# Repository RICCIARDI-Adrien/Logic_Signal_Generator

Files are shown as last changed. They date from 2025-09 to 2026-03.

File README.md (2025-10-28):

# Logic Signal Generator

A versatile multi-protocol 1.8V/3.3V/5V logic signal generator powered by a PIC18F25K50.

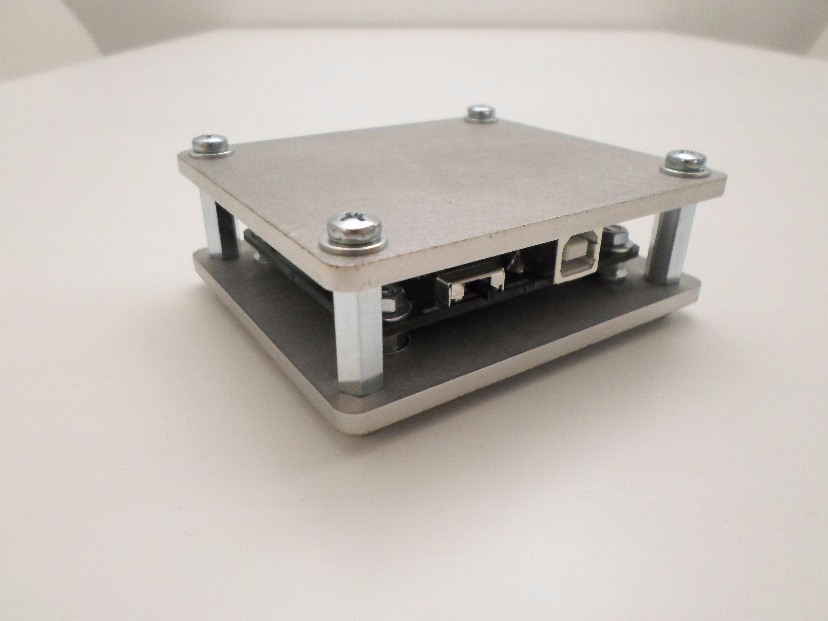
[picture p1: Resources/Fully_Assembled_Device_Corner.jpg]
Fully assembled device corner


## Features

* 8 independant channels featuring several standard protocols.
* The microcontroller hardware I2C, UART, SPI and PWM modules are used to provide the signal timings.
* Entirely USB-powered, no need for an external power supply.
* Dedicated power supplies and ground connector to easily power the device under test. The embedded 1.8V and 3.3V power supplies are each able to provide 500mA (these power supplies are derived from the USB power, so the available power could be limited by the USB port).
* On-board switch to quickly select the logic signals output voltage (1.8V, 3.3V or 5V).
* The USB interface is managed by the microcontroller itself and provides a standard USB serial port to the host.
* Simple shell-based text interface through the serial port to interactively configure and define the logic signals to generate.
* The signals are doubled on the output connector to easily connect a logic analyzer.
* PICkit-compatible standard connector to easily program the on-board microcontroller firmware.
* Compact and robust casing designed to bring the signal generator on field.

## Hardware

Bare PCB :
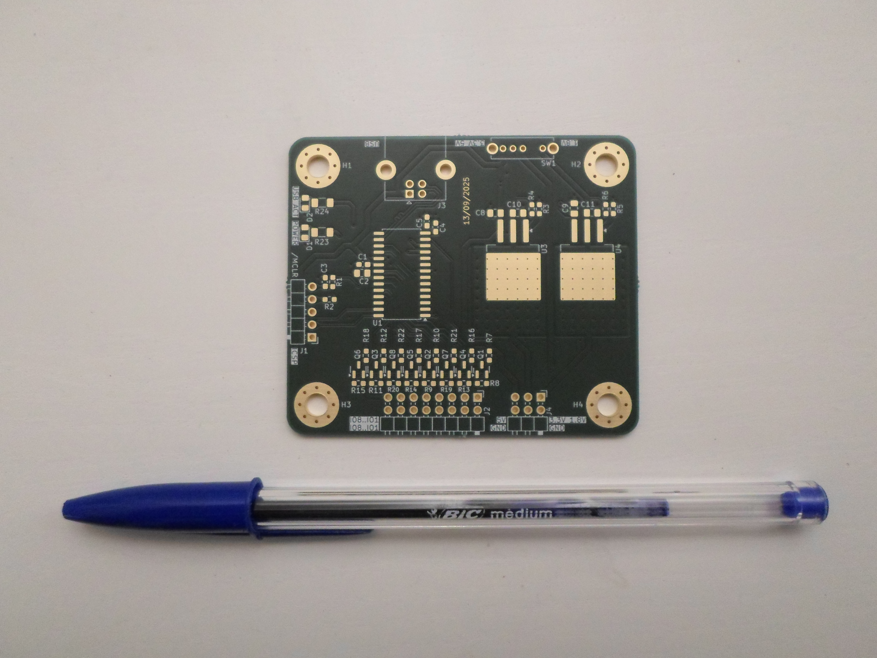
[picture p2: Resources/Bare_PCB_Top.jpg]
Bare PCB front view

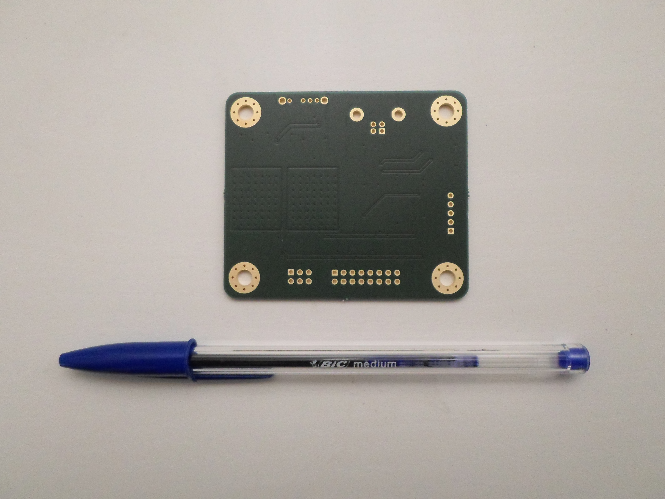
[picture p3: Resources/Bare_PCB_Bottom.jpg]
Bare PCB bottom view


Assembled PCB :
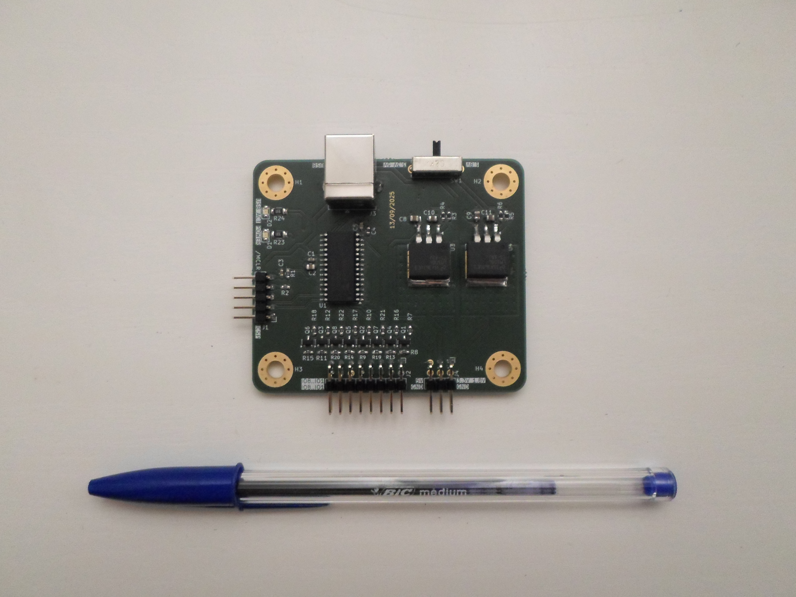
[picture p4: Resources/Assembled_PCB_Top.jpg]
Assembled PCB front view

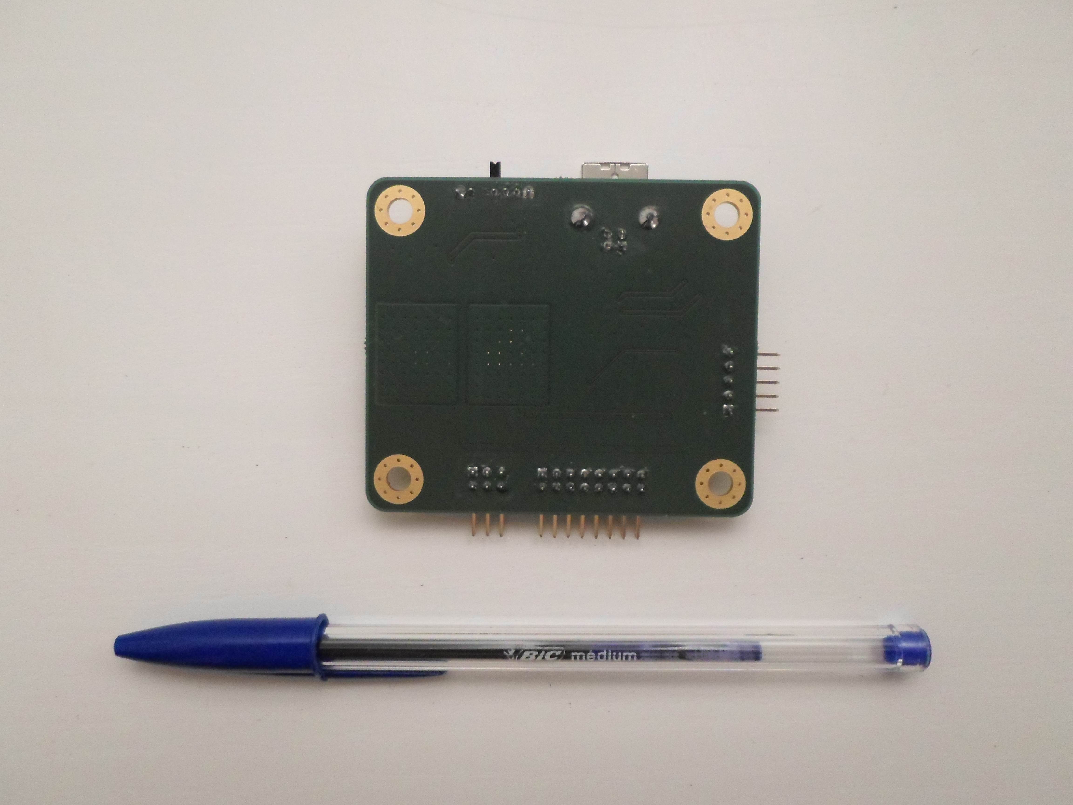
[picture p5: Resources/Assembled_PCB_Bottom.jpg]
Assembled PCB bottom view


## Casing

The casing is made of 4mm-thick 304 stainless steel.

Bare plates :
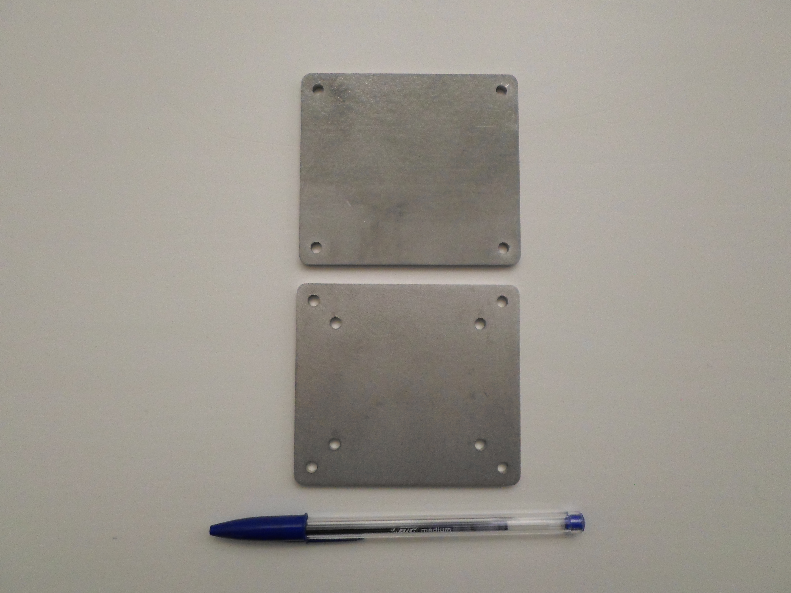
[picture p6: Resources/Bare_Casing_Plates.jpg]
Bare plates


Assembled bottom plate, with PCB and hex spacers :
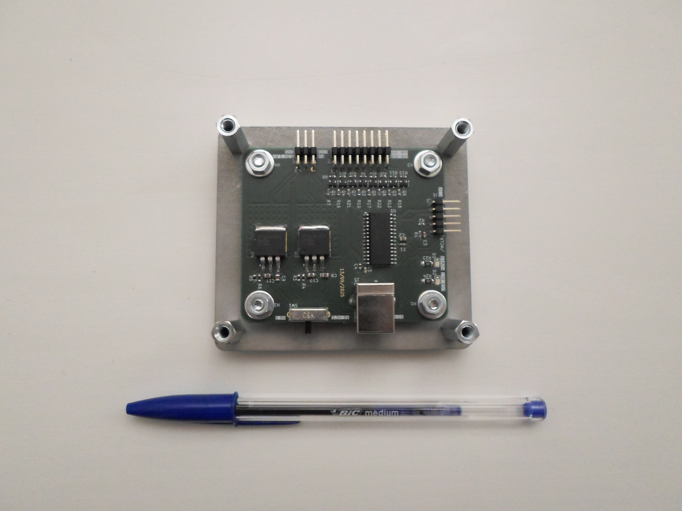
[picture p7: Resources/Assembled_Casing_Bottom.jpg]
Assembled bottom plate


Fully assembled device :  
Top view :
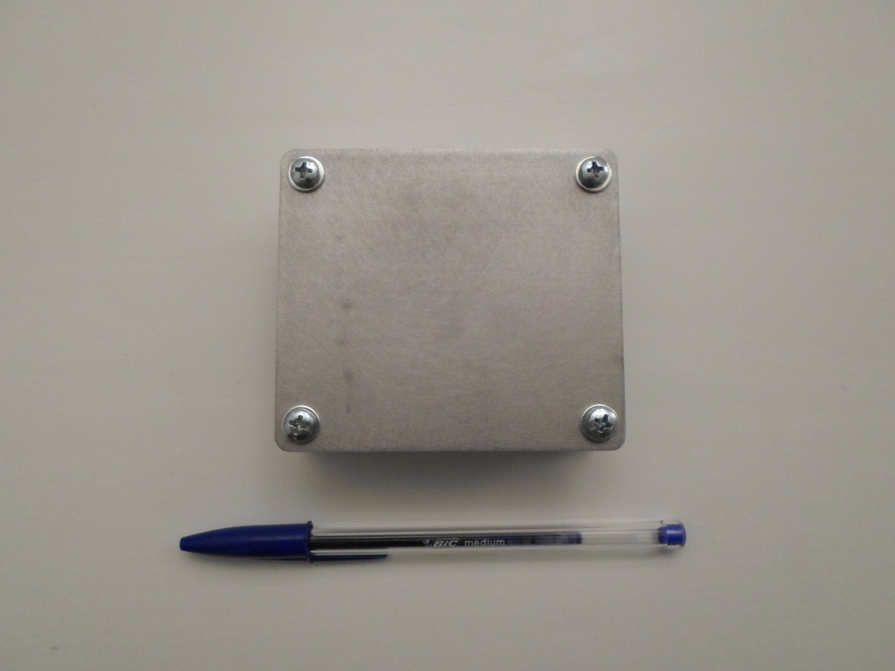
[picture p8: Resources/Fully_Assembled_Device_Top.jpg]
Fully assembled device

IO and power connectors :
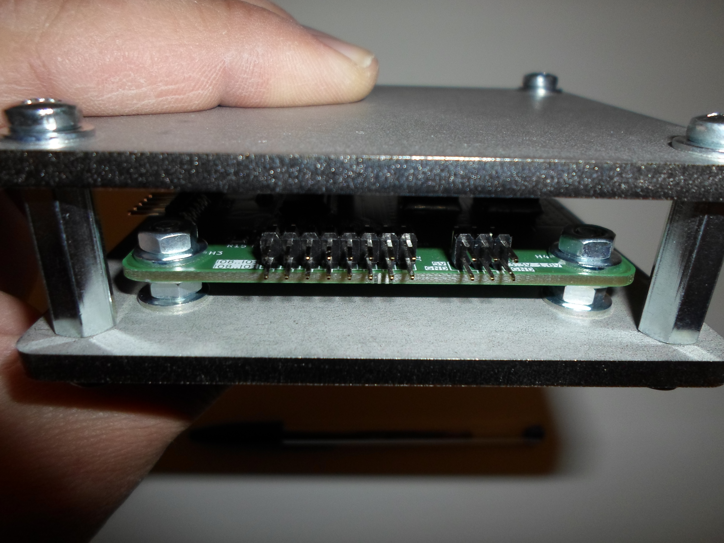
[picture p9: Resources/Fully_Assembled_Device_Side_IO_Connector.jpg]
Fully assembled device side IO connector

USB connector and IO voltage selection switch :
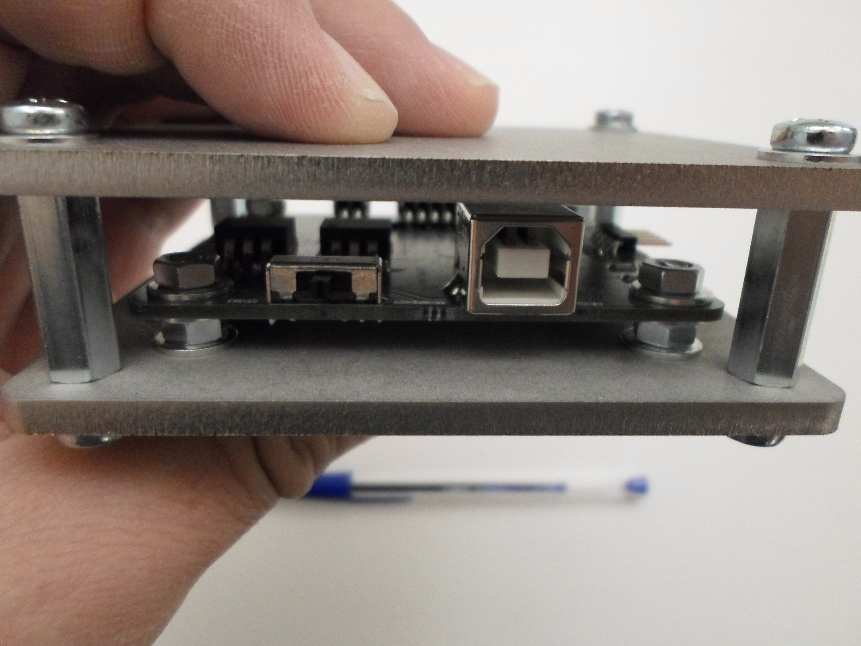
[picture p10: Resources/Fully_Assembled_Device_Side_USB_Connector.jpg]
Fully assembled device side USB connector

Power and activity LEDs along with microcontroller programming connector :
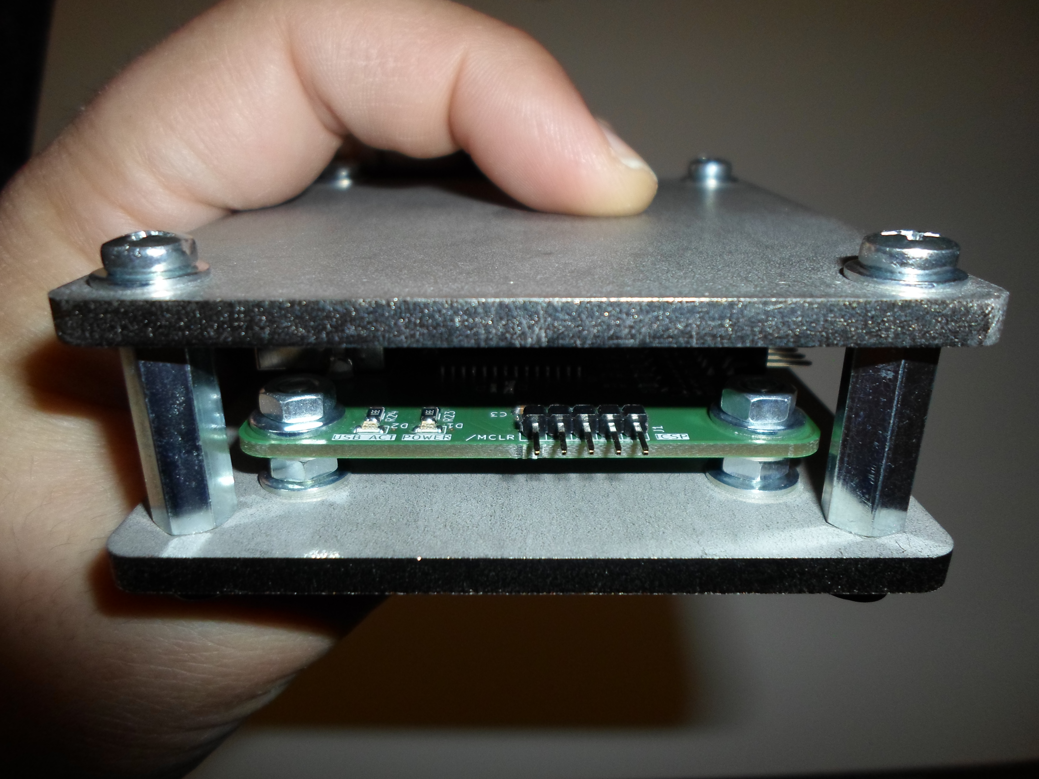
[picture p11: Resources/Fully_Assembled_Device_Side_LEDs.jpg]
Fully assembled device side LEDs


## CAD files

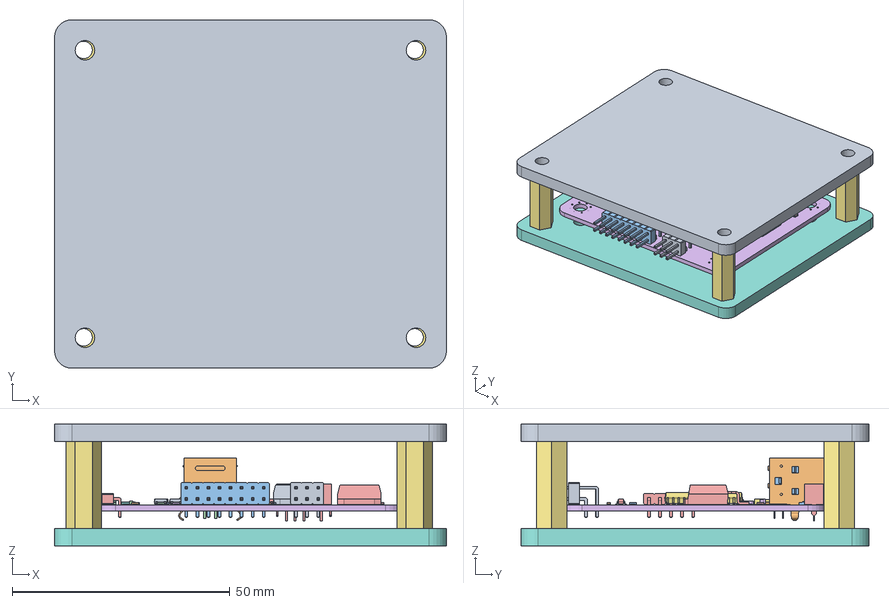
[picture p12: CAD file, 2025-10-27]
Casing/Casing.FCStd
90.0 x 80.0 x 28.0 mm
SOT-23
R_0603_1608Metric
R_0603_1608Metric001
C_0603_1608Metric
OS103011MA7QP1
SOT-024
R_0603_1608Metric002
C_0603_1608Metric001
R_0603_1608Metric003
_USB-B-S-TH_S
_USB-B-S-B-TH_B
_USB-B-S-TH_P
R_0603_1608Metric004
R_0603_1608Metric005
C_0805_2012Metric
SOT-025
PinHeader_2x03_P2.54mm_Horizontal
R_0603_1608Metric006
R_0603_1608Metric007
R_0603_1608Metric008
C_0805_2012Metric001
C_0805_2012Metric002
LED_0805_2012Metric
R_1206_3216Metric
SOT-026
R_1206_3216Metric001
R_0603_1608Metric009
LED_0805_2012Metric001
Logic_Signal_Generator_PCB 1.27.1
R_0603_1608Metric010
SOIC-28W_7.5x17.9mm_P1.27mm
R_0603_1608Metric011
R_0603_1608Metric012
R_0603_1608Metric013
PinHeader_2x08_P2.54mm_Horizontal
R_0603_1608Metric014
R_0603_1608Metric015
C_0603_1608Metric002
R_0603_1608Metric016
R_0603_1608Metric017
SOT-027
R_0603_1608Metric018
R_0603_1608Metric019
SOT-028
PinHeader_1x05_P2.54mm_Horizontal
C_0805_2012Metric003
C_0805_2012Metric004
R_0603_1608Metric020
Logic_Signal_Generator_PCB 1.27.002
R_0603_1608Metric021
SOT-029
C_0603_1608Metric003
SOT-030
Logic_Signal_Generator_PCB
Hex_Spacer x 4
Plate_Bottom
Plate_Top

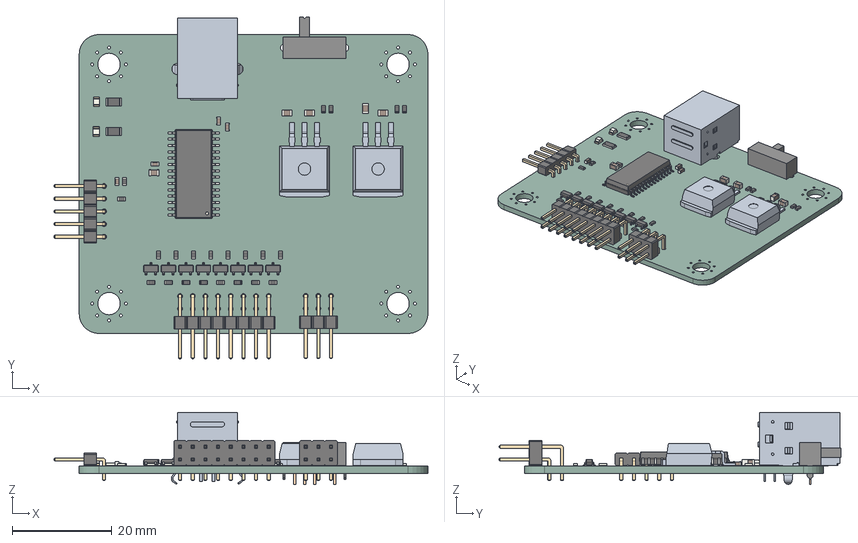
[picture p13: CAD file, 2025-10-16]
Casing/PCB.step
75.0 x 68.6 x 14.5 mm
SOT-23 x 8
R_0603_1608Metric x 22
C_0603_1608Metric x 4
OS103011MA7QP1
_USB-B-S-TH_S
_USB-B-S-B-TH_B
_USB-B-S-TH_P
C_0805_2012Metric x 5
PinHeader_2x03_P2.54mm_Horizontal
LED_0805_2012Metric x 2
R_1206_3216Metric x 2
Logic_Signal_Generator_PCB 1.27.1 x 2
SOIC-28W_7.5x17.9mm_P1.27mm
PinHeader_2x08_P2.54mm_Horizontal
PinHeader_1x05_P2.54mm_Horizontal
Logic_Signal_Generator_PCB

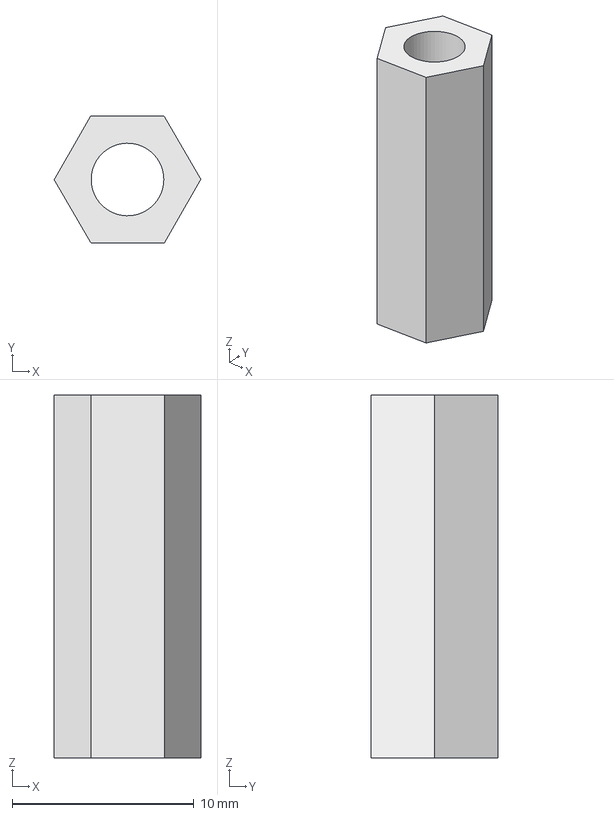
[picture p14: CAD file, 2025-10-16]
Casing/Hex_Spacer.step
8.08 x 7.01 x 20.0 mm

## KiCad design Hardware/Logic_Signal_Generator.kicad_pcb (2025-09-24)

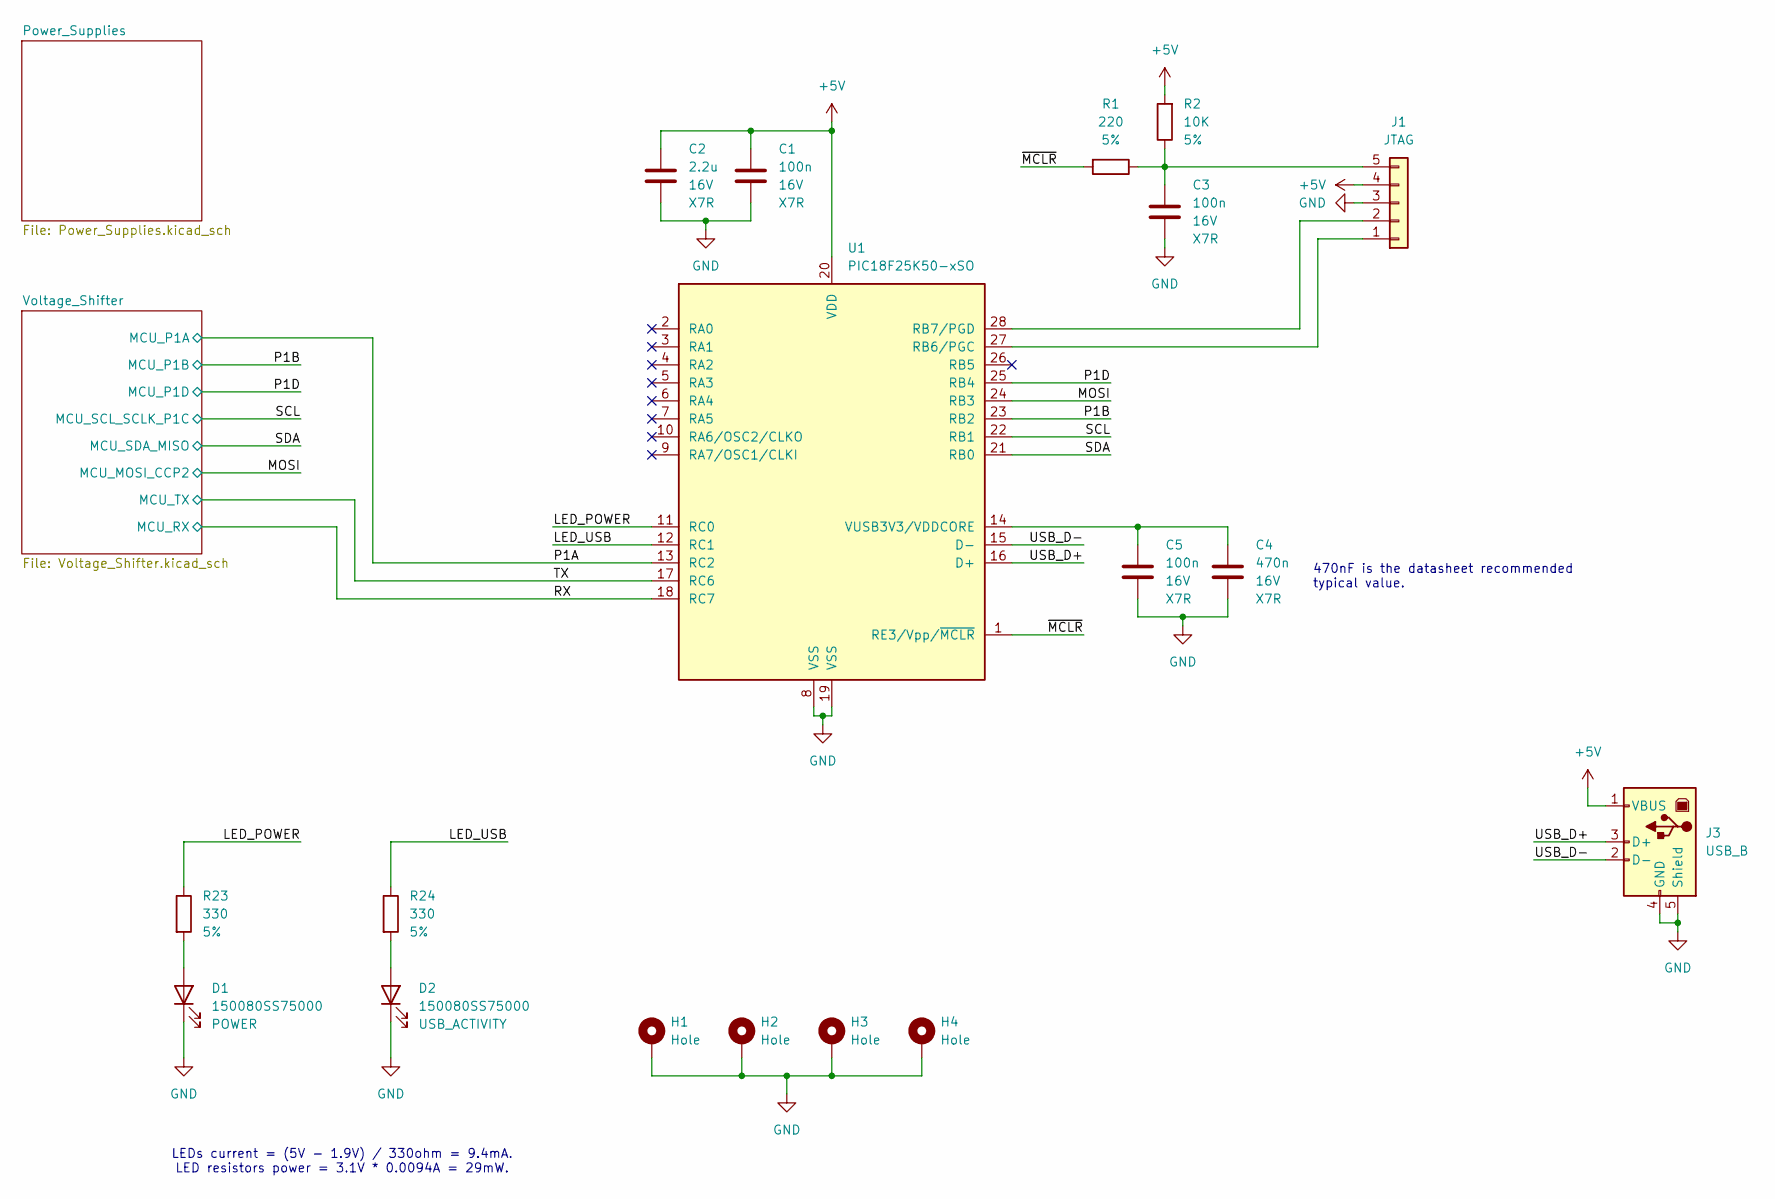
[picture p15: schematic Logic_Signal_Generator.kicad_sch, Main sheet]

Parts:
C1, C3, C5: 100n; C_0603_1608Metric_Pad1.08x0.95mm_HandSolder
C2: 2.2u; C_0805_2012Metric_Pad1.18x1.45mm_HandSolder
C4: 470n; C_0603_1608Metric_Pad1.08x0.95mm_HandSolder
D1, D2: 150080SS75000; LED_0805_2012Metric_Pad1.15x1.40mm_HandSolder
H1, H2, H3, H4: Hole; MountingHole_4.5mm_Pad_Via
J1: JTAG; PinHeader_1x05_P2.54mm_Horizontal
J3: USB_B; USB_B_Lumberg_2411_02_Horizontal
R1: 220; R_0603_1608Metric_Pad0.98x0.95mm_HandSolder
R2: 10K; R_0603_1608Metric_Pad0.98x0.95mm_HandSolder
R23, R24: 330; R_1206_3216Metric_Pad1.30x1.75mm_HandSolder
U1: PIC18F25K50-xSO; SOIC-28W_7.5x17.9mm_P1.27mm

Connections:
+5V: C1.1, C2.1, J1.4, J3.1 (VBUS), R2.2, U1.20 (VDD); also elsewhere on the board
/LED_POWER: R23.1, U1.11 (RC0)
/LED_USB: R24.1, U1.12 (RC1)
/MOSI: U1.24 (RB3); also elsewhere on the board
/P1A: U1.13 (RC2); also elsewhere on the board
/P1B: U1.23 (RB2); also elsewhere on the board
/P1D: U1.25 (RB4); also elsewhere on the board
/RX: U1.18 (RC7); also elsewhere on the board
/SCL: U1.22 (RB1); also elsewhere on the board
/SDA: U1.21 (RB0); also elsewhere on the board
/TX: U1.17 (RC6); also elsewhere on the board
/USB_D+: J3.3 (D+), U1.16 (D+)
/USB_D-: J3.2 (D-), U1.15 (D-)
/~MCLR: R1.2, U1.1 (RE3/Vpp/~MCLR)
GND: C1.2, C2.2, C3.2, C4.2, C5.2, D1.1 (K), D2.1 (K), H1.1, H2.1, H3.1, H4.1, J1.3, J3.4 (GND), J3.5 (Shield), U1.8 (VSS), U1.19 (VSS); also elsewhere on the board
unnamed: D1.2 (A), R23.2
unnamed: D2.2 (A), R24.2
unnamed: J1.1, U1.27 (RB6/PGC)
unnamed: J1.2, U1.28 (RB7/PGD)
unnamed: C3.1, J1.5, R1.1, R2.1
unnamed: C4.1, C5.1, U1.14 (VUSB3V3/VDDCORE)

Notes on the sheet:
LEDs current = (5V - 1.9V) / 330ohm = 9.4mA. LED resistors power = 3.1V * 0.0094A = 29mW.
470nF is the datasheet recommended typical value.

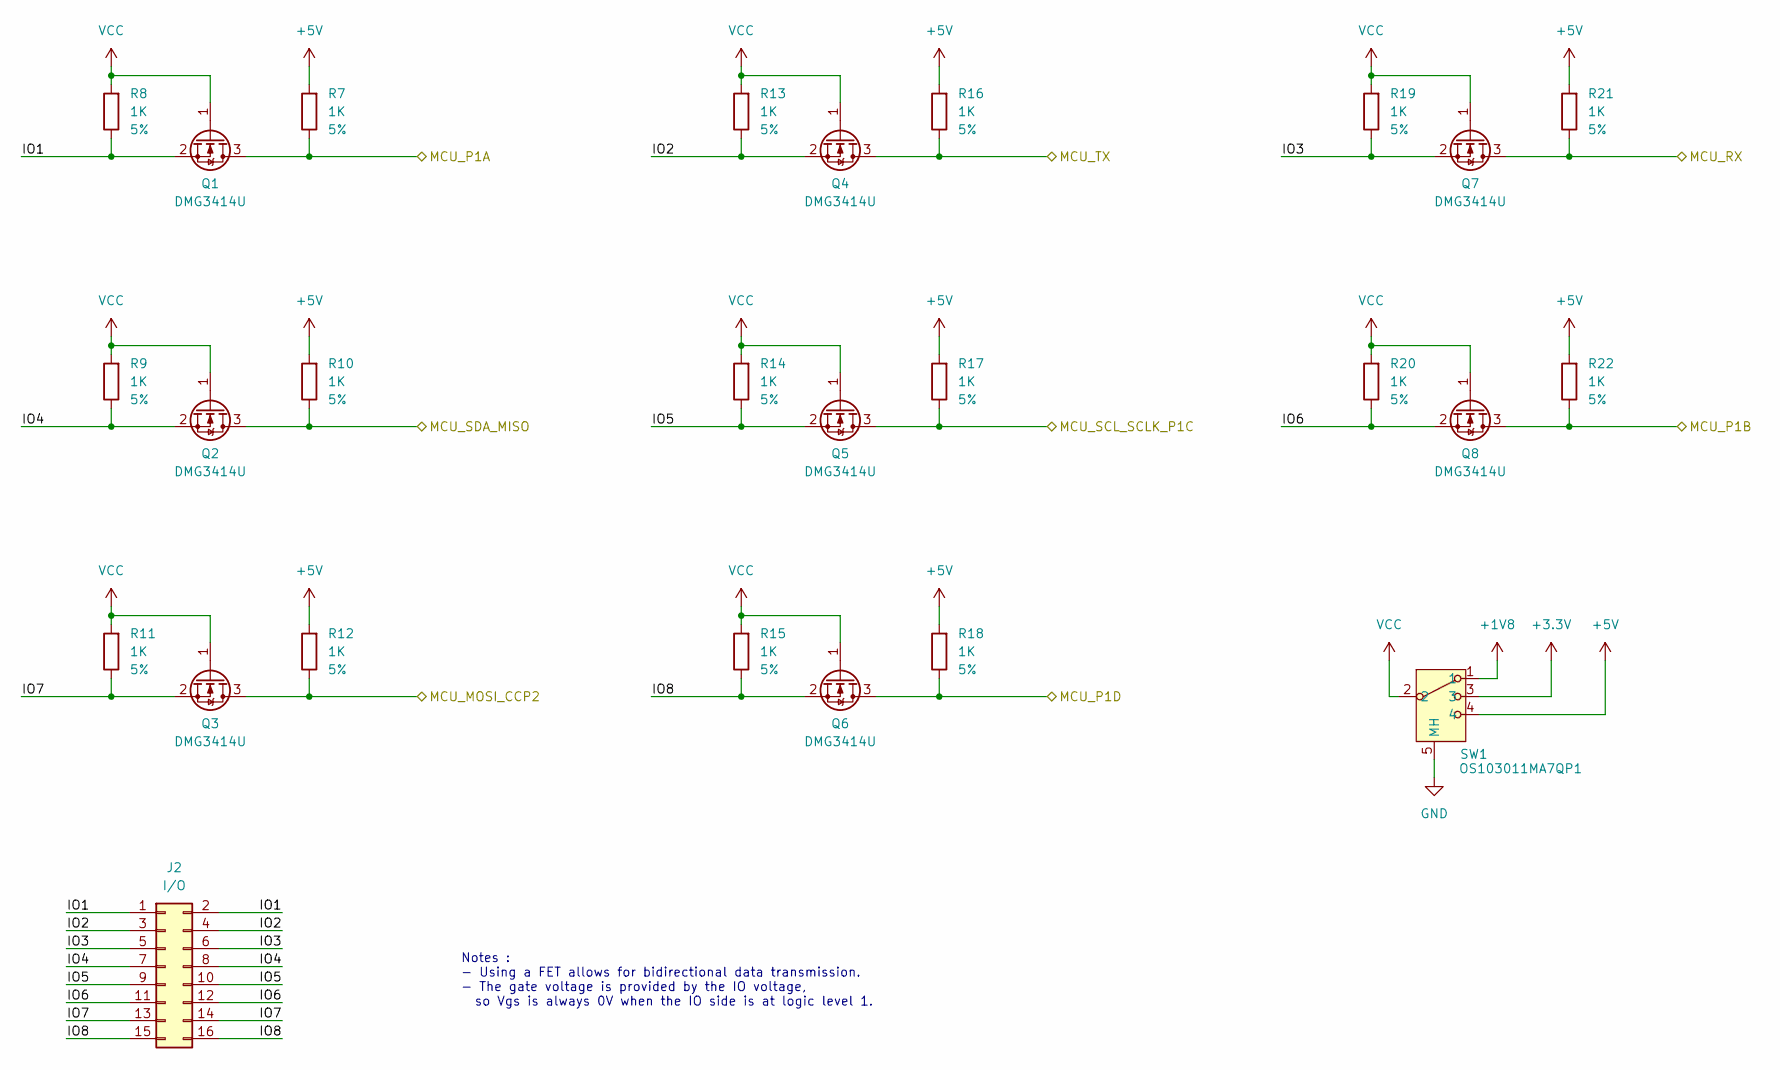
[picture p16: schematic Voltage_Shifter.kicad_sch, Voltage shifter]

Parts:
J2: I/O; PinHeader_2x08_P2.54mm_Horizontal
Q1, Q2, Q3, Q4, Q5, Q6, Q7, Q8: DMG3414U; SOT-23
R7, R8, R9, R10, R11, R12, R13, R14, R15, R16, R17, R18, R19, R20, R21, R22: 1K; R_0603_1608Metric_Pad0.98x0.95mm_HandSolder
SW1: OS103011MA7QP1

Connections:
+1V8: SW1.1; also elsewhere on the board
+3.3V: SW1.3; also elsewhere on the board
+5V: R7.2, R10.2, R12.2, R16.2, R17.2, R18.2, R21.2, R22.2, SW1.4; also elsewhere on the board
/MOSI: Q3.3 (D), R12.1; also elsewhere on the board
/P1A: Q1.3 (D), R7.1; also elsewhere on the board
/P1B: Q8.3 (D), R22.1; also elsewhere on the board
/P1D: Q6.3 (D), R18.1; also elsewhere on the board
/RX: Q7.3 (D), R21.1; also elsewhere on the board
/SCL: Q5.3 (D), R17.1; also elsewhere on the board
/SDA: Q2.3 (D), R10.1; also elsewhere on the board
/TX: Q4.3 (D), R16.1; also elsewhere on the board
/Voltage_Shifter/IO1: J2.1, J2.2, Q1.2 (S), R8.1
/Voltage_Shifter/IO2: J2.3, J2.4, Q4.2 (S), R13.1
/Voltage_Shifter/IO3: J2.5, J2.6, Q7.2 (S), R19.1
/Voltage_Shifter/IO4: J2.7, J2.8, Q2.2 (S), R9.1
/Voltage_Shifter/IO5: J2.9, J2.10, Q5.2 (S), R14.1
/Voltage_Shifter/IO6: J2.11, J2.12, Q8.2 (S), R20.1
/Voltage_Shifter/IO7: J2.13, J2.14, Q3.2 (S), R11.1
/Voltage_Shifter/IO8: J2.15, J2.16, Q6.2 (S), R15.1
GND: SW1.5 (MH), SW1.6 (MH); also elsewhere on the board
VCC: Q1.1 (G), Q2.1 (G), Q3.1 (G), Q4.1 (G), Q5.1 (G), Q6.1 (G), Q7.1 (G), Q8.1 (G), R8.2, R9.2, R11.2, R13.2, R14.2, R15.2, R19.2, R20.2, SW1.2

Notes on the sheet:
Notes : - Using a FET allows for bidirectional data transmission. - The gate voltage is provided by the IO voltage, so Vgs is always 0V when the IO side is at logic level 1.

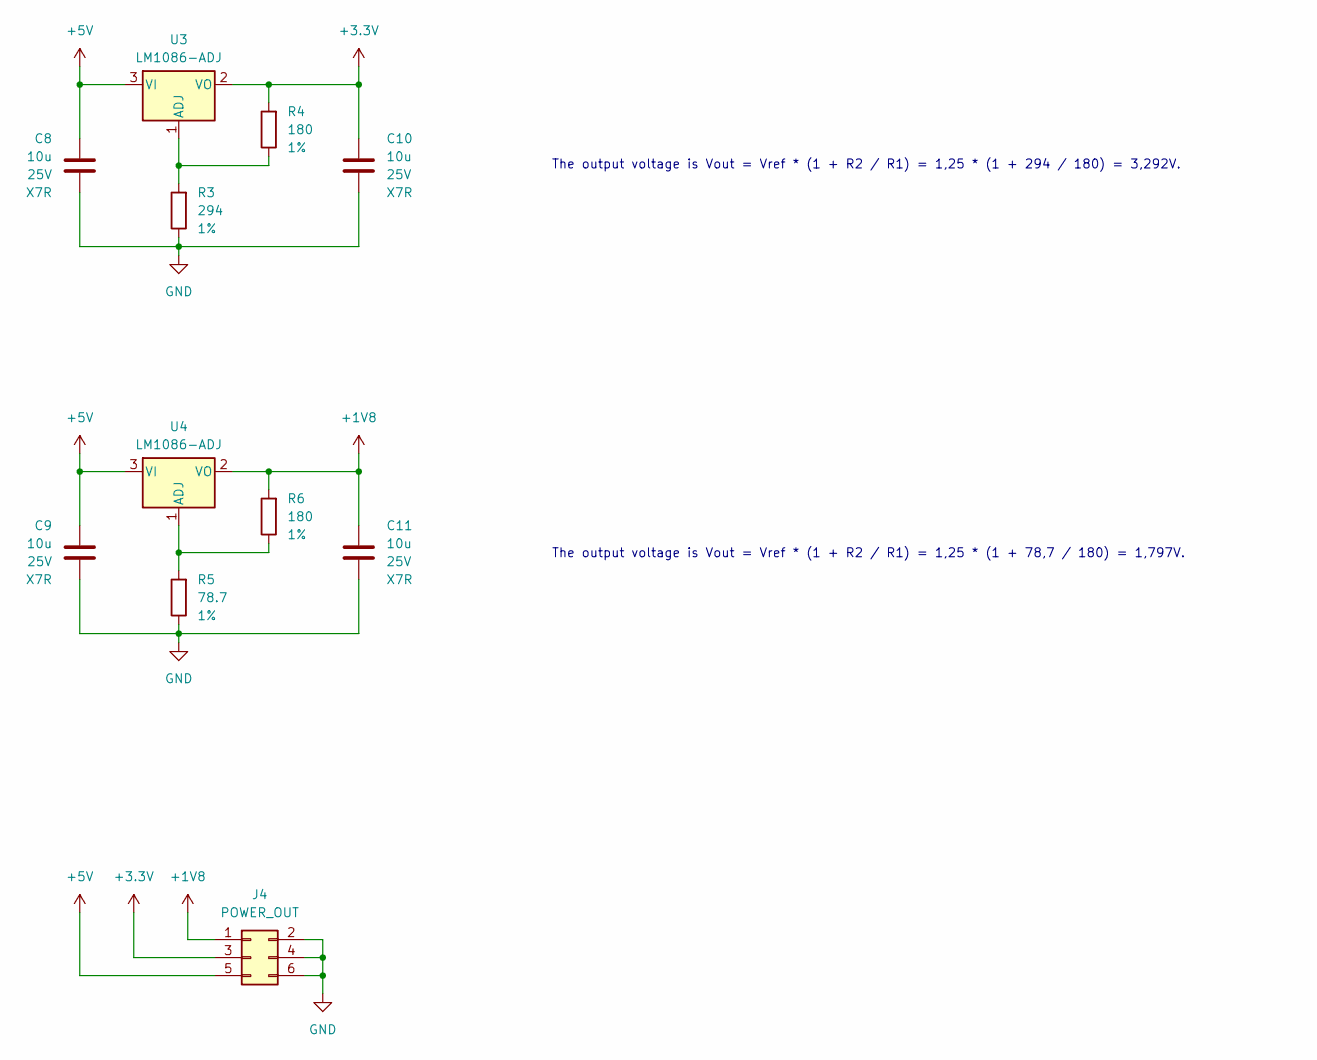
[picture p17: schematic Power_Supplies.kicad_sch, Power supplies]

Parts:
C8, C9, C10, C11: 10u; C_0805_2012Metric_Pad1.18x1.45mm_HandSolder
J4: POWER_OUT; PinHeader_2x03_P2.54mm_Horizontal
R3: 294; R_0603_1608Metric_Pad0.98x0.95mm_HandSolder
R4, R6: 180; R_0603_1608Metric_Pad0.98x0.95mm_HandSolder
R5: 78.7; R_0603_1608Metric_Pad0.98x0.95mm_HandSolder
U3, U4: LM1086-ADJ; TO-263-3_TabPin2

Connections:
+1V8: C11.1, J4.1, R6.2, U4.2 (VO); also elsewhere on the board
+3.3V: C10.1, J4.3, R4.2, U3.2 (VO); also elsewhere on the board
+5V: C8.1, C9.1, J4.5, U3.3 (VI), U4.3 (VI); also elsewhere on the board
GND: C8.2, C9.2, C10.2, C11.2, J4.2, J4.4, J4.6, R3.1, R5.1; also elsewhere on the board
unnamed: R3.2, R4.1, U3.1 (ADJ)
unnamed: R5.2, R6.1, U4.1 (ADJ)

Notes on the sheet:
The output voltage is Vout = Vref * (1 + R2 / R1) = 1,25 * (1 + 294 / 180) = 3,292V.
The output voltage is Vout = Vref * (1 + R2 / R1) = 1,25 * (1 + 78,7 / 180) = 1,797V.

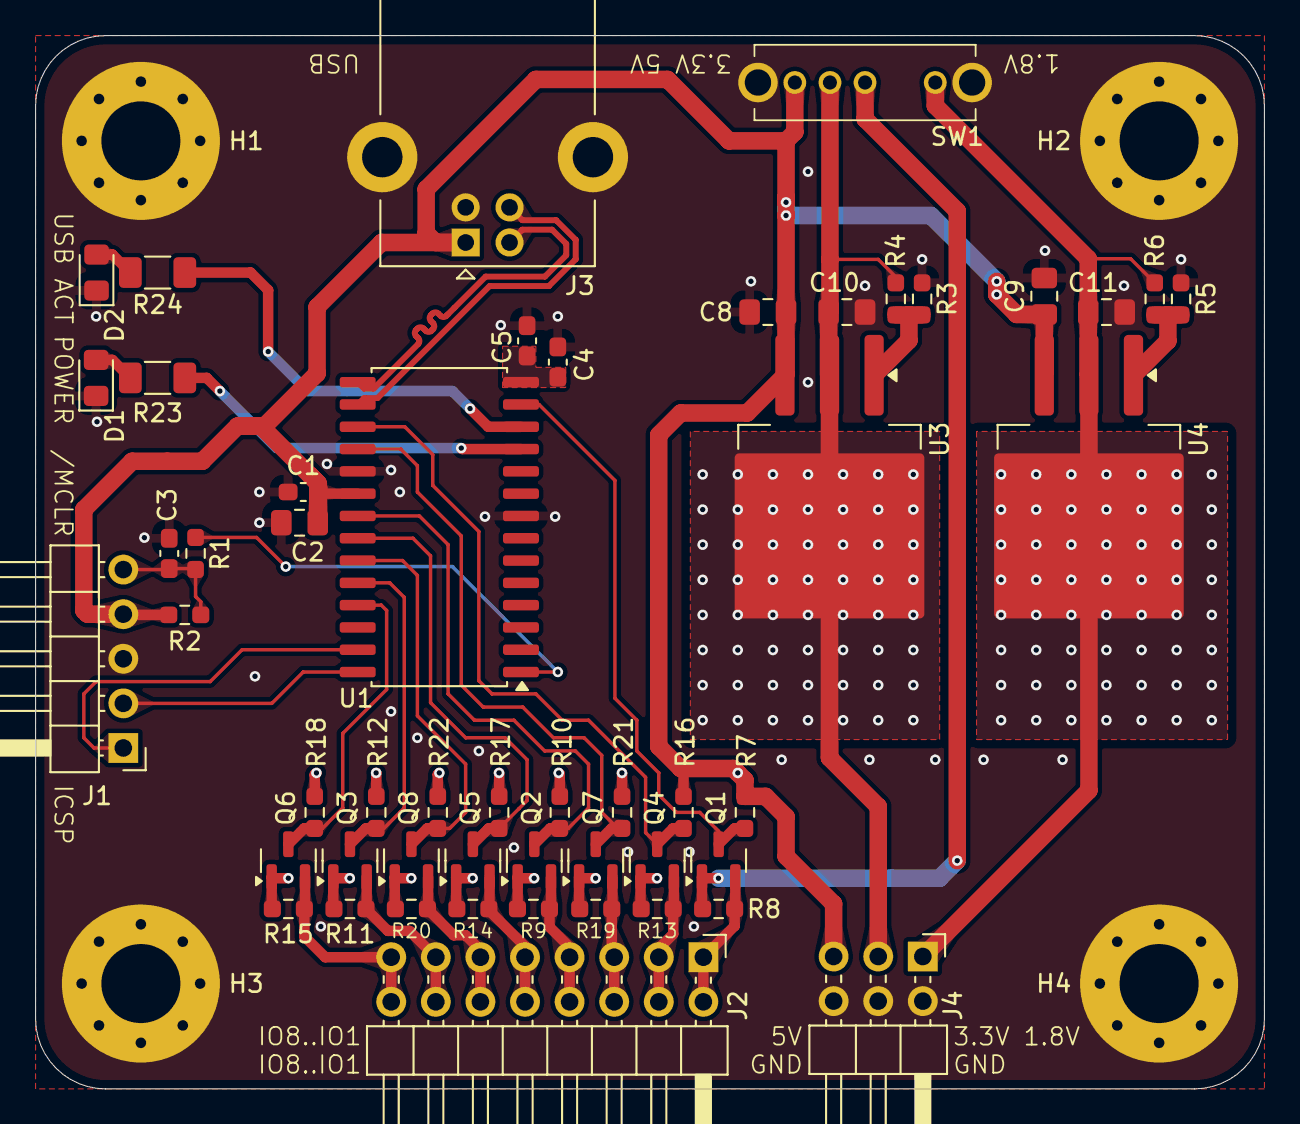
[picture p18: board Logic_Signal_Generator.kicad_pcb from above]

Board: 2 copper layers, 70.0 x 60.0 mm, 55 parts (0 on the bottom side), 34 nets.

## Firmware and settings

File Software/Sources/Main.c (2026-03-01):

/** @file Main.c
 * Logic signal generator entry point and main loop.
 * @author Adrien RICCIARDI
 */
#include <Log.h>
#include <Shell.h>
#include <UART.h>
#include <USB_Communications.h>
#include <xc.h>

//-------------------------------------------------------------------------------------------------
// Microcontroller configuration
//-------------------------------------------------------------------------------------------------
// CONFIG1L register
#pragma config CPUDIV = NOCLKDIV, CFGPLLEN = ON, PLLSEL = PLL3X // CPU uses system clock with no division, always enable the PLL, select a 3x clock multiplier factor for the PLL
// CONFIG1H register
#pragma config IESO = OFF, FCMEN = OFF, PCLKEN = ON, FOSC = INTOSCIO // Disable unneeded oscillator switchover, disable fail-safe clock monitor, always enable the primary oscillator, select the internal oscillator as the primary oscillator
// CONFIG2L register
#pragma config nLPBOR = OFF, BORV = 285, BOREN = SBORDIS, nPWRTEN = ON // Disable the low-power brown-out reset, enable the brown-out reset with the highest available voltage, enable the power up timer
// CONFIG2H register
#pragma config WDTEN = OFF // Disable the watchdog timer
// CONFIG3H register
#pragma config MCLRE = ON, SDOMX = RB3, PBADEN = OFF, CCP2MX = RC1 // Enable /MCLR, keep the SPI SDO pin on port B, configure the port B pins as digital I/Os, move the CCP2 pin to port C
// CONFIG4L register
#pragma config DEBUG = OFF, XINST = OFF, ICPRT = OFF, LVP = ON, STVREN = ON // Disable the debugger, disable the extended instruction set, disable the in-circuit debug/programming port, enable the low-voltage programming, stack overflow or underflow will reset the MCU
// CONFIG5L register
#pragma config CP3 = OFF, CP2 = OFF, CP1 = OFF, CP0 = OFF // Disable all code protections
// CONFIG5H register
#pragma config CPD = OFF, CPB = OFF // Disable data EEPROM code protection, disable boot block code protection
// CONFIG6L register
#pragma config WRT3 = ON, WRT2 = ON, WRT1 = ON, WRT0 = ON // Enable blocks write protection
// CONFIG6H register
#pragma config WRTD = OFF, WRTB = ON, WRTC = ON // Allow to write to the EEPROM, prevent writing to the boot block or the configuration registers
// CONFIG7L register
#pragma config EBTR3 = OFF, EBTR2 = OFF, EBTR1 = OFF, EBTR0 = OFF // Disable blocks read protection
// CONFIG7H register
#pragma config EBTRB = OFF // Disable boot block read protection

//-------------------------------------------------------------------------------------------------
// Private types
//-------------------------------------------------------------------------------------------------
/** The format of the CDC class specific endpoint descriptors. */
typedef struct
{
	TUSBCoreDescriptorInterface Control_Interface;
	TUSBCommunicationsFunctionalDescriptorHeader Header;
	TUSBCommunicationsFunctionalDescriptorAbstractControlManagement Management;
	TUSBCommunicationsFunctionalDescriptorUnion Union;
	TUSBCoreDescriptorEndpoint Notification_Endpoint;
	TUSBCoreDescriptorInterface Data_Interface;
	TUSBCoreDescriptorEndpoint Data_Out_Endpoint;
	TUSBCoreDescriptorEndpoint Data_In_Endpoint;
} __attribute__((packed)) TMainUSBCommunicationsClassSpecificEndpointDescriptor;

//-------------------------------------------------------------------------------------------------
// Private variables
//-------------------------------------------------------------------------------------------------
/** All application USB strings. */
static const unsigned short Main_USB_Descriptor_String_Data_0 = USB_CORE_LANGUAGE_ID_FRENCH_STANDARD;
static const unsigned short Main_USB_Descriptor_String_Data_Manufacturer[] = { 'R', 'I', 'C', 'C', 'I', 'A', 'R', 'D', 'I', ' ', 'D', 'A', 'T', 'A', ' ', 'S', 'Y', 'S', 'T', 'E', 'M' };
static const unsigned short Main_USB_Descriptor_String_Data_Product[] = { 'L', 'o', 'g', 'i', 'c', ' ', 'S', 'i', 'g', 'n', 'a', 'l', ' ', 'G', 'e', 'n', 'e', 'r', 'a', 't', 'o', 'r' };
static const unsigned short Main_USB_Descriptor_String_Data_Serial_Number[]  = { '0', '.', '1' };
static const TUSBCoreDescriptorString Main_USB_String_Descriptors[4] =
{
	{
		.bLength = USB_CORE_DESCRIPTOR_SIZE_STRING(sizeof(Main_USB_Descriptor_String_Data_0)),
		.bDescriptorType = USB_CORE_DESCRIPTOR_TYPE_STRING,
		.Pointer_Data = &Main_USB_Descriptor_String_Data_0
	},
	{
		.bLength = USB_CORE_DESCRIPTOR_SIZE_STRING(sizeof(Main_USB_Descriptor_String_Data_Manufacturer)),
		.bDescriptorType = USB_CORE_DESCRIPTOR_TYPE_STRING,
		.Pointer_Data = &Main_USB_Descriptor_String_Data_Manufacturer
	},
	{
		.bLength = USB_CORE_DESCRIPTOR_SIZE_STRING(sizeof(Main_USB_Descriptor_String_Data_Product)),
		.bDescriptorType = USB_CORE_DESCRIPTOR_TYPE_STRING,
		.Pointer_Data = &Main_USB_Descriptor_String_Data_Product
	},
	{
		.bLength = USB_CORE_DESCRIPTOR_SIZE_STRING(sizeof(Main_USB_Descriptor_String_Data_Serial_Number)),
		.bDescriptorType = USB_CORE_DESCRIPTOR_TYPE_STRING,
		.Pointer_Data = &Main_USB_Descriptor_String_Data_Serial_Number
	}
};

/** The interfaces definitions for the unique USB configuration. */
static const TMainUSBCommunicationsClassSpecificEndpointDescriptor Main_USB_Communications_Class_Specific_Endpoint_Descriptors =
{
	.Control_Interface =
	{
		.bLength = sizeof(TUSBCoreDescriptorInterface),
		.bDescriptorType = USB_CORE_DESCRIPTOR_TYPE_INTERFACE,
		.bInterfaceNumber = 0,
		.bAlternateSetting = 0,
		.bNumEndpoints = 1,
		.bInterfaceClass = USB_CORE_INTERFACE_CLASS_CODE_COMMUNICATIONS,
		.bInterfaceSubClass = USB_CORE_INTERFACE_SUB_CLASS_CODE_ABSTRACT_CONTROL_MODEL,
		.bInterfaceProtocol = USB_CORE_INTERFACE_PROTOCOL_CODE_ITU_V250,
		.iInterface = 0
	},
	.Header =
	{
		.bFunctionLength = sizeof(TUSBCommunicationsFunctionalDescriptorHeader),
		.bDescriptorType = USB_COMMUNICATIONS_FUNCTIONAL_DESCRIPTOR_TYPE_INTERFACE,
		.bDescriptorSubtype = USB_COMMUNICATIONS_FUNCTIONAL_DESCRIPTOR_SUB_TYPE_HEADER,
		.bcdCDC = USB_COMMUNICATIONS_SPECIFICATION_RELEASE_NUMBER
	},
	.Management =
	{
		.bFunctionLength = sizeof(TUSBCommunicationsFunctionalDescriptorAbstractControlManagement),
		.bDescriptorType = USB_COMMUNICATIONS_FUNCTIONAL_DESCRIPTOR_TYPE_INTERFACE,
		.bDescriptorSubtype = USB_COMMUNICATIONS_FUNCTIONAL_DESCRIPTOR_SUB_TYPE_ABSTRACT_CONTROL_MANAGEMENT,
		.bmCapabilities = 0 // TODO configure the capabilities
	},
	.Union =
	{
		.bFunctionLength = sizeof(TUSBCommunicationsFunctionalDescriptorUnion),
		.bDescriptorType = USB_COMMUNICATIONS_FUNCTIONAL_DESCRIPTOR_TYPE_INTERFACE,
		.bDescriptorSubtype = USB_COMMUNICATIONS_FUNCTIONAL_DESCRIPTOR_SUB_TYPE_UNION,
		.bControlInterface = 0,
		.bSubordinateInterface0 = 1
	},
	.Notification_Endpoint =
	{
		.bLength = sizeof(TUSBCoreDescriptorEndpoint),
		.bDescriptorType = USB_CORE_DESCRIPTOR_TYPE_ENDPOINT,
		.bEndpointAddress = 1 | USB_CORE_DESCRIPTOR_ENDPOINT_ATTRIBUTE_ENDPOINT_ADDRESS_DIRECTION_IN,
		.bmAttributes = USB_CORE_DESCRIPTOR_ENDPOINT_ATTRIBUTE_TRANSFER_TYPE_INTERRUPT,
		.wMaxPacketSize = 8,
		.bInterval = 255
	},
	.Data_Interface =
	{
		.bLength = sizeof(TUSBCoreDescriptorInterface),
		.bDescriptorType = USB_CORE_DESCRIPTOR_TYPE_INTERFACE,
		.bInterfaceNumber = 1,
		.bAlternateSetting = 0,
		.bNumEndpoints = 2,
		.bInterfaceClass = USB_CORE_INTERFACE_CLASS_CODE_DATA_INTERFACE,
		.bInterfaceSubClass = USB_CORE_INTERFACE_SUB_CLASS_CODE_NONE,
		.bInterfaceProtocol = USB_CORE_INTERFACE_PROTOCOL_CODE_NONE,
		.iInterface = 0
	},
	.Data_Out_Endpoint =
	{
		.bLength = sizeof(TUSBCoreDescriptorEndpoint),
		.bDescriptorType = USB_CORE_DESCRIPTOR_TYPE_ENDPOINT,
		.bEndpointAddress = 2 | USB_CORE_DESCRIPTOR_ENDPOINT_ATTRIBUTE_ENDPOINT_ADDRESS_DIRECTION_OUT,
		.bmAttributes = USB_CORE_DESCRIPTOR_ENDPOINT_ATTRIBUTE_TRANSFER_TYPE_BULK,
		.wMaxPacketSize = USB_CORE_ENDPOINT_PACKETS_SIZE,
		.bInterval = 1
	},
	.Data_In_Endpoint =
	{
		.bLength = sizeof(TUSBCoreDescriptorEndpoint),
		.bDescriptorType = USB_CORE_DESCRIPTOR_TYPE_ENDPOINT,
		.bEndpointAddress = 3 | USB_CORE_DESCRIPTOR_ENDPOINT_ATTRIBUTE_ENDPOINT_ADDRESS_DIRECTION_IN,
		.bmAttributes = USB_CORE_DESCRIPTOR_ENDPOINT_ATTRIBUTE_TRANSFER_TYPE_BULK,
		.wMaxPacketSize = USB_CORE_ENDPOINT_PACKETS_SIZE,
		.bInterval = 1
	}
};

/** The application unique USB configuration descriptor. */
static const TUSBCoreDescriptorConfiguration Main_USB_Configuration_Descriptor = // Store this into the program memory to save some RAM
{
	.bLength = USB_CORE_DESCRIPTOR_SIZE_CONFIGURATION,
	.bDescriptorType = USB_CORE_DESCRIPTOR_TYPE_CONFIGURATION,
	.wTotalLength = USB_CORE_DESCRIPTOR_SIZE_CONFIGURATION + sizeof(Main_USB_Communications_Class_Specific_Endpoint_Descriptors),
	.bNumInterfaces = 2,
	.bConfigurationValue = 1,
	.iConfiguration = 0,
	.bmAttributes = 0, // The device is not self-powered and does not support the remove wakeup feature
	.bMaxPower = 250, // Take as much power as possible, just in case the logic signal generator needs to power a board
	.Pointer_Interfaces_Data = &Main_USB_Communications_Class_Specific_Endpoint_Descriptors
};

/** Each used hardware USB endpoint configuration. */
static TUSBCoreHardwareEndpointConfiguration Main_USB_Hardware_Endpoints_Configuration[] =
{
	// Control endpoint
	{
		.Enabled_Directions = USB_CORE_HARDWARE_ENDPOINT_DIRECTION_OUT | USB_CORE_HARDWARE_ENDPOINT_DIRECTION_IN,
		.Out_Transfer_Callback = USBCommunicationsHandleControlRequestCallback,
		.In_Transfer_Callback = NULL
	},
	// CDC ACM notification
	{
		.Enabled_Directions = USB_CORE_HARDWARE_ENDPOINT_DIRECTION_IN,
		.Out_Transfer_Callback = NULL,
		.In_Transfer_Callback = NULL
	},
	// CDC ACM data OUT
	{
		.Enabled_Directions = USB_CORE_HARDWARE_ENDPOINT_DIRECTION_OUT,
		.Out_Transfer_Callback = USBCommunicationsHandleDataReceptionCallback, // Only this endpoint can receive user data
		.In_Transfer_Callback = NULL
	},
	// CDC ACM data IN
	{
		.Enabled_Directions = USB_CORE_HARDWARE_ENDPOINT_DIRECTION_OUT | USB_CORE_HARDWARE_ENDPOINT_DIRECTION_IN,
		.Out_Transfer_Callback = NULL,
		.In_Transfer_Callback = USBCommunicationsHandleDataTransmissionFlowControlCallback
	}
};

/** The application USB device descriptor, see chapter 5.1.1 of the Class Definitions for Communications Devices revision 1.2. */
static const TUSBCoreDescriptorDevice Main_USB_Device_Descriptor = // Store this into the program memory to save some RAM
{
	.bLength = USB_CORE_DESCRIPTOR_SIZE_DEVICE,
	.bDescriptorType = USB_CORE_DESCRIPTOR_TYPE_DEVICE,
	.bcdUSB = USB_CORE_BCD_USB_SPECIFICATION_RELEASE_NUMBER,
	.bDeviceClass = USB_CORE_DEVICE_CLASS_CODE_COMMUNICATIONS,
	.bDeviceSubClass = USB_CORE_DEVICE_SUB_CLASS_CODE_NONE, // Tell the host to check each interface
	.bDeviceProtocol = USB_CORE_DEVICE_PROTOCOL_CODE_NONE, // Unused
	.bMaxPacketSize0 = USB_CORE_ENDPOINT_PACKETS_SIZE,
	.idVendor = 0x1240, // Use the Microchip VID for now
	.idProduct = 0xFADA, // Use a random product ID
	.bcdDevice = 0x0001, // Version 0.1 for now
	.iManufacturer = 1,
	.iProduct = 2,
	.iSerialNumber = 3,
	.bNumConfigurations = 1,
	.Pointer_Configurations = &Main_USB_Configuration_Descriptor,
	.Pointer_Strings = Main_USB_String_Descriptors,
	.String_Descriptors_Count = USB_CORE_ARRAY_SIZE(Main_USB_String_Descriptors),
	.Pointer_Hardware_Endpoints_Configuration = Main_USB_Hardware_Endpoints_Configuration,
	.Hardware_Endpoints_Count = USB_CORE_ARRAY_SIZE(Main_USB_Hardware_Endpoints_Configuration)
};

//-------------------------------------------------------------------------------------------------
// Private functions
//-------------------------------------------------------------------------------------------------
/** High-priority interrupts handler entry point. */
void __interrupt(high_priority) MainInterruptHandlerHighPriority(void)
{
	if (USB_CORE_IS_INTERRUPT_FIRED()) USBCoreInterruptHandler();
}

/** Low-priority interrupts handler entry point. */
void __interrupt(low_priority) MainInterruptHandlerLowPriority(void)
{
	if (USB_CORE_IS_ACTIVITY_LED_INTERRUPT_FIRED()) USBCoreActivityLedInterruptHandler();
}

//-------------------------------------------------------------------------------------------------
// Entry point
//-------------------------------------------------------------------------------------------------
void main(void)
{
	char String_Command_Line[USB_CORE_ENDPOINT_PACKETS_SIZE + 1]; // Using the USB packet size grants that the entered command line will fit in a single packet and no data byte can be lost during a copy, the +1 is to make room for the terminating zero
	unsigned char Result;

	// Configure the system clock at 48MHz
	OSCCON = 0x70; // Select a 16MHz frequency output for the internal oscillator, select the primary clock configured by the fuses (which is the internal oscillator)
	__delay_ms(10); // Add a little delay to make sure that the PLL is locked (2ms should be enough, but take some margin)

	// Initialize the modules
	UARTInitialize();

	// Configure the interrupts
	RCONbits.IPEN = 1; // Enable priority levels on interrupts
	INTCON |= 0xC0; // Enable high and low priority interrupts

	// Light the "power" LED
	LATCbits.LATC0 = 1;
	TRISCbits.TRISC0 = 0; // Set the pin as output (there is no analog on this pin)

	LOG(1, "\033[33mInitialization complete.\033[0m");

	// Initialize the USB stack now that all modules are operational
	USBCoreInitialize(&Main_USB_Device_Descriptor);
	USBCommunicationsInitialize(3);

	// Wait until the host has configured the CDC ACM link
	while (!USBCommunicationsIsCommunicationEstablished());
	__delay_ms(100); // Give a bit of delay to finalize the USB CDC ACM configuration

	// Process the user commands
	while (1)
	{
		ShellReadCommandLine(String_Command_Line, sizeof(String_Command_Line));

		// Execute the command only if one has been provided
		if (String_Command_Line[0] != 0)
		{
			Result = ShellProcessCommand(String_Command_Line);
			if (Result == 1) USBCommunicationsWriteString("\r\nUnknown command.");
		}
	}
}

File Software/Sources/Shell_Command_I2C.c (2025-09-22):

/** @file Shell_Command_I2C.c
 * Implement all I2C-related shell commands.
 * @author Adrien RICCIARDI
 */
#include <Log.h>
#include <MSSP.h>
#include <Shell.h>
#include <Shell_Commands.h>
#include <stdio.h>
#include <USB_Communications.h>

//-------------------------------------------------------------------------------------------------
// Private constants
//-------------------------------------------------------------------------------------------------
/** Set to 1 to enable the log messages, set to 0 to disable them. */
#define SHELL_I2C_IS_LOGGING_ENABLED 1

//-------------------------------------------------------------------------------------------------
// Public functions
//-------------------------------------------------------------------------------------------------
void ShellCommandI2CCallback(char *Pointer_String_Arguments)
{
	/** The maximum amount of commands that can be read from the command line. */
	#define MAXIMUM_COMMANDS_COUNT 16

	/** All supported command types. */
	typedef enum
	{
		I2C_COMMAND_TYPE_GENERATE_START,
		I2C_COMMAND_TYPE_GENERATE_STOP,
		I2C_COMMAND_TYPE_READ,
		I2C_COMMAND_TYPE_WRITE
	} TI2CCommandType;

	/** Efficiently store the command parameters. */
	typedef struct
	{
		TI2CCommandType Type;
		union
		{
			unsigned long Bytes_Count; //!< For a read operation, how many bytes to read.
			unsigned char Data; //!< For a write operation, the data byte to write.
		};
	} TI2CCommand;

	TI2CCommand Commands[MAXIMUM_COMMANDS_COUNT], *Pointer_Command = Commands;
	unsigned char Commands_Count = 0, Length = 0, i, Is_Start_Generated = 0;
	unsigned long Value;
	// Both buffers are never used at the same time, so make sure to reuse the same memory area
	union
	{
		char String_Temporary[32];
		unsigned char Buffer_Temporary[32];
	} Buffers;

	// Parse all commands to validate the command line syntax
	while (*Pointer_String_Arguments != 0)
	{
		Pointer_String_Arguments = ShellExtractNextToken(Pointer_String_Arguments, &Length);
		if (Pointer_String_Arguments == NULL) break;
		LOG(SHELL_I2C_IS_LOGGING_ENABLED, "Command (not zero terminated) : \"%s\".", Pointer_String_Arguments);

		// Parse the next command
		switch (*Pointer_String_Arguments)
		{
			case '[':
				LOG(SHELL_I2C_IS_LOGGING_ENABLED, "Found an \"I2C START\" command.");
				Pointer_Command->Type = I2C_COMMAND_TYPE_GENERATE_START;
				break;

			case ']':
				LOG(SHELL_I2C_IS_LOGGING_ENABLED, "Found an \"I2C STOP\" command.");
				Pointer_Command->Type = I2C_COMMAND_TYPE_GENERATE_STOP;
				break;

			case 'r':
				LOG(SHELL_I2C_IS_LOGGING_ENABLED, "Found an \"I2C READ\" command, parsing it.");

				// Make sure that the bytes count was provided to the read command
				if (Length == 1)
				{
					USBCommunicationsWriteString("\r\nError : please provide the amount of bytes to read with the \"r\" command.");
					return;
				}

				// Convert the bytes count to binary
				if (ShellConvertNumericalArgumentToBinary(Pointer_String_Arguments + 1, Length - 1, &Value) != 0) // Add one to bypass the 'r' character
				{
					USBCommunicationsWriteString("\r\nError : the bytes count argument provided to the read command is invalid.");
					return;
				}

				// Fill the command
				LOG(SHELL_I2C_IS_LOGGING_ENABLED, "Asked to read %lu bytes.", Value);
				Pointer_Command->Type = I2C_COMMAND_TYPE_READ;
				Pointer_Command->Bytes_Count = Value;
				break;

			default:
				LOG(SHELL_I2C_IS_LOGGING_ENABLED, "Trying to find a write command.");

				// Convert the bytes count to binary
				if (ShellConvertNumericalArgumentToBinary(Pointer_String_Arguments, Length, &Value) != 0)
				{
					USBCommunicationsWriteString("\r\nError : a command is invalid.");
					return;
				}

				// Only bytes are allowed
				if (Value > 255)
				{
					USBCommunicationsWriteString("\r\nError : only bytes are allowed as a write command data, make sure the value is in range [0,255].");
					return;
				}

				// Fill the command
				Pointer_Command->Type = I2C_COMMAND_TYPE_WRITE;
				Pointer_Command->Data = (unsigned char) Value;
				LOG(SHELL_I2C_IS_LOGGING_ENABLED, "Found a write command with value 0x%02X.",  Pointer_Command->Data);
				break;
		}

		// Go to the next available command slot
		Commands_Count++;
		if (Commands_Count > MAXIMUM_COMMANDS_COUNT)
		{
			USBCommunicationsWriteString("\r\nError : the maximum amount of commands has been reached.");
			return;
		}
		Pointer_Command++;
	}

	// Tell the user that no command was provided
	if (Commands_Count == 0)
	{
		USBCommunicationsWriteString("\r\nNo I2C command was given.");
		return;
	}
	LOG(SHELL_I2C_IS_LOGGING_ENABLED, "Parsed %u commands, now executing them.", Commands_Count);

	// Configure the I2C interface
	MSSPSetFunctioningMode(MSSP_FUNCTIONING_MODE_I2C);

	// Execute the commands
	Pointer_Command = Commands;
	for (i = 0; i < Commands_Count; i++)
	{
		LOG(SHELL_I2C_IS_LOGGING_ENABLED, "Executing command %u.", i);
		switch (Pointer_Command->Type)
		{
			case I2C_COMMAND_TYPE_GENERATE_START:
				// Differentiate between an I2C start and a repeated start
				if (Is_Start_Generated)
				{
					LOG(SHELL_I2C_IS_LOGGING_ENABLED, "Generating a REPEATED START.");
					MSSPI2CGenerateRepeatedStart();
				}
				else
				{
					LOG(SHELL_I2C_IS_LOGGING_ENABLED, "Generating a START.");
					MSSPI2CGenerateStart();
					Is_Start_Generated = 1;
				}
				break;

			case I2C_COMMAND_TYPE_GENERATE_STOP:
				LOG(SHELL_I2C_IS_LOGGING_ENABLED, "Generating a STOP.");
				MSSPI2CGenerateStop();
				Is_Start_Generated = 0;
				break;

			case I2C_COMMAND_TYPE_READ:
			{
				unsigned char Is_Acknowledge_Generated, *Pointer_Data_Buffer, Chunk_Size, Bytes_To_Display_Count;
				unsigned long Remaining_Bytes_Count = Pointer_Command->Bytes_Count, Address = 0;

				// Read all bytes one chunk at a time
				snprintf(Buffers.String_Temporary, sizeof(Buffers.String_Temporary), "\r\nReading %lu bytes.\r\n", Remaining_Bytes_Count);
				USBCommunicationsWriteString(Buffers.String_Temporary);
				LOG(SHELL_I2C_IS_LOGGING_ENABLED, "Reading %lu bytes.", Remaining_Bytes_Count);

				while (Remaining_Bytes_Count > 0)
				{
					// Find the next chunk size
					if (Remaining_Bytes_Count >= sizeof(Buffers.Buffer_Temporary)) Chunk_Size = sizeof(Buffers.Buffer_Temporary);
					else Chunk_Size = (unsigned char) Remaining_Bytes_Count;
					Bytes_To_Display_Count = Chunk_Size;

					// Read the chunk of data
					Pointer_Data_Buffer = Buffers.Buffer_Temporary;
					while (Chunk_Size > 0)
					{
						// Send a NACK if this is the last byte to read
						if (Remaining_Bytes_Count == 1) Is_Acknowledge_Generated = 0;
						else Is_Acknowledge_Generated = 1;

						// Read the byte
						LOG(SHELL_I2C_IS_LOGGING_ENABLED, "Reading the next byte and sending %s to the slave device.", Is_Acknowledge_Generated ? "ACK" : "NACK");
						*Pointer_Data_Buffer = MSSPI2CReadByte(Is_Acknowledge_Generated);
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

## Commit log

2020-04-02 [Hardware] Started schematic. Microcontroller, voltage translators and pin headers are present.
    [Motherboard.kicad_pcb, Motherboard.sch]
2020-04-02 [Hardware] Added LDO and led to schematic.
    [Motherboard.sch]
2020-04-02 [Hardware] Added FTDI FIFO and logic signals output voltage switch to schematic.
    [Motherboard.kicad_pcb, Motherboard.sch]
2020-04-02 [Hardware] Placed components on PCB.
    [Motherboard.kicad_pcb, Motherboard.sch]
2020-04-02 [Hardware] Added PCB mounting holes.
    [Motherboard.kicad_pcb, Motherboard.sch]
2020-04-15 [Hardware] Started PCB routing. Switched to 4 layers to have power supply planes.
    [Motherboard.kicad_pcb, Motherboard.sch]
2020-04-15 [Hardware] Finished PCB routing. Switched two schematic signals to help routing.
    [Motherboard.kicad_pcb, Motherboard.sch]
2020-04-15 [Hardware] Improved some component names placement on PCB.
    [Motherboard.kicad_pcb]
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2025-04-17 [Software] Added a basic version of the UART module with a test code.
2025-04-17 [Software] Added the logging module that outputs log messages to the UART.
2025-04-22 [Software] Started exploring and implementing the USB support. The only thing the USB device is currently capable of is to attach to the USB bus.
2025-04-22 [Software] Added the dual-priority interrupts support and the generic handler for the USB peripheral.
    Only the USB 'reset' interrupt is detected for now, and only for test purpose.
    [Main.c]
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2025-05-20 [Software] Fixed the USB string descriptor indexes in the device descriptor : they start at index 1 instead of 0.
    [Main.c]
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2025-07-26 [Software] Added the support for the USB Device Qualifier descriptor in the enumeration process.
    Also added the ability to stall an endpoint.
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2025-08-03 [Software] Fixed consecutive USB OUT transfers not triggering the transfer interrupt by clearing the USB interrupt flags in the correct order.
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2025-08-30 [Software] Fixed two bugs in the ShellConvertNumericalArgumentToBinary() function.
    - The string terminating character swapped with a 0 was not restored in case no digits were provided after the 'h' character.
    - After converting a hexadecimal number, the command line string was messed by one character.
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2025-08-30 [Software] Fixed the shell "i2c" command reporting incorrect slave write NACK.
    [Shell_Command_I2C.c]
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2025-09-02 [Software] Fixed the "i2c-scan" shell command hanging after a slave sent an ACK.
    [Shell_Command_I2C.c]
2025-09-02 [Hardware] Removed the previous project to restart from scratch.
    [Motherboard.kicad_pcb, Motherboard.sch]
2025-09-02 [Hardware] Added a new empty project.
    [Logic_Signal_Generator.kicad_pcb, Logic_Signal_Generator.kicad_sch]
2025-09-02 [Hardware] Added the microcontroller and the supporting hardware to the schematic.
    [Logic_Signal_Generator.kicad_sch]
2025-09-02 [Hardware] Added the voltage translator and the USB connector to the schematic.
    [Logic_Signal_Generator.kicad_sch]
2025-09-03 [Hardware] Added to the schematic the two LDOs to generate the +3.3V and +1.8V voltages.
    [Logic_Signal_Generator.kicad_sch, Power_Supplies.kicad_sch]
2025-09-09 [Hardware] Replaced the TXS0108E voltage shifter by discrete N-MOSFET transistors.
    The TXS0108E was not working well during prototyping, it had difficulties determining the direction of the data transfer.
    The microcontroller power supply has been switched from +3.3V to +5V to always provide the highest supported voltage on the N-MOSFET drain.
    [Logic_Signal_Generator.kicad_sch, Voltage_Shifter.kicad_sch]
2025-09-11 [Hardware] Added the output voltage selection switch.
    [Voltage_Shifter.kicad_sch]
2025-09-11 [Hardware] Added a pin header connector to provide the output power supply.
    [Power_Supplies.kicad_sch, Voltage_Shifter.kicad_sch]
2025-09-11 [Hardware] Added the power and USB activity LEDs to the schematic.
    [Logic_Signal_Generator.kicad_sch]
2025-09-13 [Hardware] Added the missing pin number 3 to the OS103011MA7QP1 switch.
    [Voltage_Shifter.kicad_sch]
2025-09-13 [Hardware] Made an initial placement of the components on the PCB.
    [Logic_Signal_Generator.kicad_pcb, Logic_Signal_Generator.kicad_sch]
2025-09-13 [Hardware] Added the mounting holes and the PCB edges.
    [Logic_Signal_Generator.kicad_pcb, Logic_Signal_Generator.kicad_sch]
2025-09-13 [Hardware] Enabled PCB teardrops.
    [Logic_Signal_Generator.kicad_pcb]
2025-09-13 [Hardware] Added the PCB stackup information.
    Such information come from the "aisler-2-layer-hd-drc" board from the https://github.com/AislerHQ/aisler-support GitHub repository.
    [Logic_Signal_Generator.kicad_pcb]
2025-09-13 [Hardware] Routed the USB full speed traces trying to keep a matched length and a 45ohm odd differential impedance.
    [Logic_Signal_Generator.kicad_pcb]
2025-09-13 [Hardware] Routed the voltage regulators.
    [Logic_Signal_Generator.kicad_pcb, Power_Supplies.kicad_sch]
2025-09-13 [Hardware] Routed all but the LEDs.
    Changed the IOs order to help the routing.
    [Logic_Signal_Generator.kicad_pcb, Voltage_Shifter.kicad_sch]
2025-09-13 [Hardware] Routed the LEDs and changed their current limiting resistors package.
    [Logic_Signal_Generator.kicad_pcb, Logic_Signal_Generator.kicad_sch]
2025-09-13 [Hardware] Added the LDO thermal pads and the connectors and LEDs silkscreen marking.
    [Logic_Signal_Generator.kicad_pcb]
2025-09-13 [Hardware] Fixed all remaining silkscreen-related PCB warnings.
    [Logic_Signal_Generator.kicad_pcb]
2025-09-13 [Hardware] Added the USB connector 3D model to the PCB.
    [Logic_Signal_Generator.kicad_pcb]
2025-09-13 [Hardware] Added the missing pin no connect indicators to the schematic.
    [Logic_Signal_Generator.kicad_sch]
2025-09-13 [Hardware] Set the grid and drilling coordinates origin onto the PCB.
    [Logic_Signal_Generator.kicad_pcb]
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2025-09-13 [Hardware] Improved the USB connector and the "/MCLR" silkscreen marking on the PCB.
    [Logic_Signal_Generator.kicad_pcb]
2025-09-13 [Hardware] Added the missing value for the switch into the schematic.
    [Voltage_Shifter.kicad_sch]
2025-09-13 [Hardware] Moved the LEDs description text to the Description field into the schematic."
    [Logic_Signal_Generator.kicad_sch]
2025-09-13 [Hardware] Also grouped the components per value 2 and 3 fields when exporting the bill of materials.
    [Power_Supplies.kicad_sch]
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2025-09-22 [Software] Fixed the "read" data dump displaying of the "i2c" shell command.
    [Shell_Command_I2C.c]
2025-09-24 [Hardware] Set the bill of materials and the PCB production file output paths.
    [Logic_Signal_Generator.kicad_pcb]
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2025-10-16 [Casing] Started the casing design by importing the PCB and the hex spacer models.
    [Casing.FCStd, Hex_Spacer.step, PCB.step]
2025-10-16 [Casing] Added the sketch of a full plate.
    [Casing.FCStd]
2025-10-16 [Casing] Created the bottom plate model and positionned the PCB and the hex spacers.
    [Casing.FCStd]
2025-10-16 [Casing] Added the top plate.
    [Casing.FCStd]
2025-10-27 [Casing] Added the 2D technical drawings that can be exported to DXF.
    [Casing.FCStd]
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
